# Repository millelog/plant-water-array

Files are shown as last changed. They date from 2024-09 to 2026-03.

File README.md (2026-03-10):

# Plant Water Array

Distributed plant moisture monitoring system with custom ESP32 sensors, a Python backend, and a React frontend. Devices self-register via captive portal WiFi provisioning, send periodic moisture readings, and receive code updates pushed over the LAN.

**Live demo:** [plants.loganmiller.dev](https://plants.loganmiller.dev) — click **Browse as Guest** to explore the UI with sample data (read-only).

## Features

- **Real-time moisture monitoring** — ESP32 sensors report soil moisture on a configurable interval
- **Watering log** — manual logging with notes, or auto-detection from sharp moisture spikes
- **Push notifications** — alerts via [ntfy.sh](https://ntfy.sh) when plants need water or devices go offline
- **Data insights** — drying rate analysis, aggregated trends, multi-sensor comparison charts, CSV export
- **Dashboard** — sortable/filterable plant cards, weather widget, kiosk mode for wall-mounted displays
- **Push deploys** — update device firmware over LAN with `deploy.py` (atomic file swap, SHA-256 verified)
- **Captive portal provisioning** — new devices create a WiFi AP for zero-config setup
- **PWA** — installable on mobile, responsive layout with bottom navigation
- **Light/dark themes** — dark "Greenhouse Control Room" theme by default, light mode available
- **JWT authentication** — admin login with guest demo mode
- **Database maintenance** — backup downloads, configurable data retention, health stats
- **Custom PCB** — KiCad schematic and board files in `pcb/`

## Architecture

```
ESP32 sensors  ──POST readings──▶  FastAPI backend  ◀──polls──  React frontend
  (MicroPython)                     (SQLite DB)                  (Vite + Tailwind)
```

| Component | Directory | Stack |
|---|---|---|
| Backend | `backend/` | FastAPI, SQLAlchemy, SQLite |
| Frontend | `frontend/` | React 18, TypeScript, Tailwind, Radix UI, Recharts |
| Embedded | `embeded-src/` | MicroPython on ESP32 |
| Hardware | `pcb/` | KiCad schematic + PCB |
| Deploy tool | `deploy.py` | CLI script, pushes code to devices over LAN |

## Development

### Backend
```bash
cd backend
source .venv/bin/activate
pip install -r requirements.txt
uvicorn main:app --reload --host 0.0.0.0 --port 8000
```
API docs at http://localhost:8000/docs

### Frontend
```bash
cd frontend
pnpm install
pnpm dev          # Vite dev server on port 5173
pnpm build        # TypeScript compile + Vite bundle
pnpm lint         # ESLint
```

### ESP32 Flashing
```bash
python flash_esp.py               # Auto-detect port, flash MicroPython, upload source
python flash_esp.py --sync-only   # Upload source files only
python -m mpremote connect <port> repl   # Serial console
```

### Deploying Code to Devices
```bash
python deploy.py                  # Push embeded-src/*.py to all devices over LAN
python deploy.py --dry-run        # Preview what would be deployed
python deploy.py --server URL     # Override backend URL
```

### Docker Compose
```bash
docker compose up --build         # Run backend + frontend together
```
See [docs/DEPLOYMENT.md](docs/DEPLOYMENT.md) for production deployment details.

## Data Flow

1. ESP32 boots → connects WiFi (or starts captive portal for provisioning)
2. Starts update server on port 8266 for receiving push deploys
3. Registers itself via `POST /devices/register_device`, then registers sensors via `POST /sensors/`
4. Main loop: reads moisture → `POST /readings`, heartbeat every 300s
5. Backend checks thresholds on new readings → creates alerts, sends ntfy notifications
6. Frontend polls backend APIs to display devices, readings, alerts
7. Developer runs `python deploy.py` → pushes code to all online devices, devices reboot with new code

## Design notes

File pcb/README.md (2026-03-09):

# Plant Water Array — PCB Design

Breakout board for ESP32 DevKit V1 with OLED display and 5 moisture sensor connectors.

## Board Summary

```
+--------------------------------------------------+
|                                                  |
|  [OLED 4-pin]              [ESP32 DevKit V1]    |
|   GND VCC SCL SDA           L-socket  R-socket  |
|                              (1x15)    (1x15)    |
|                                                  |
|  [J_S1] [J_S2] [J_S3] [J_S4] [J_S5]           |
|   G34    G35    G36    G39    G32               |
+--------------------------------------------------+
```

## Parts List (per board)

### PCB Connectors (solder onto the board)

| Part | Qty | Search Term | Notes |
|---|-----|---|---|
| 1x15 Female Pin Socket (2.54mm) | 2 | "1x15 pin socket 2.54mm" | ESP32 DevKit mounts into these |
| 1x4 Female Pin Socket (2.54mm) | 1 | "1x4 pin socket 2.54mm" | SSD1306 OLED plugs in here |
| JST-XH 3-pin vertical header (B3B-XH-A) | 5 | "JST XH 3 pin male header vertical" | Board-side sensor connectors |

### Sensor Cable Parts (per sensor, 5 per board)

| Part | Qty | Search Term | Notes |
|---|-----|---|---|
| JST-XH 3-pin plug housing (XHP-3) | 1 | "JST XH 3 pin female housing" | Mates with B3B-XH-A header |
| JST-XH crimp contacts (SXH-001T-P0.6) | 3 | "JST XH crimp terminal" | One per wire |
| 3-conductor wire (22-26 AWG) | ~1m | "3 conductor 24AWG wire" | Length as needed, up to ~2m |

### Quantities for 5 Boards

| Part | Total Qty |
|---|---|
| 1x15 Female Pin Socket | 10 |
| 1x4 Female Pin Socket | 5 |
| JST-XH 3-pin header (B3B-XH-A) | 25 |
| JST-XH 3-pin housing (XHP-3) | 25 |
| JST-XH crimp contacts | 75 |
| 3-conductor wire | ~25m |

### Where to Buy

- **Amazon** (fastest) — search "JST XH connector kit" (~$10-15 for assorted kit with headers + housings + crimp pins). Separately get a pack of "female pin header socket 2.54mm" (~$5-7).
- **AliExpress** (cheapest, 2-3 week shipping) — same searches, about 1/3 the price.
- **Digikey / Mouser** (exact part numbers, reliable) — B3B-XH-A ~$0.15ea, XHP-3 ~$0.10ea, SXH-001T-P0.6 ~$0.05ea, pin sockets ~$0.50ea.

A JST crimp tool (~$25) is helpful but you can solder wires directly to the crimp contacts instead.

## Pin Mapping

| Connector | Pin 1 | Pin 2 | Pin 3 | ESP32 GPIO |
|---|---|---|---|---|
| J_S1 | GND | 3V3 | SIG | GPIO 34 |
| J_S2 | GND | 3V3 | SIG | GPIO 35 |
| J_S3 | GND | 3V3 | SIG | GPIO 36 (VP) |
| J_S4 | GND | 3V3 | SIG | GPIO 39 (VN) |
| J_S5 | GND | 3V3 | SIG | GPIO 32 |
| J_OLED | GND | 3V3 | SCL (GPIO 22) | SDA (GPIO 21) |

## Generating the Netlist

```bash
cd pcb/
python generate_netlist.py
# Produces plant_water_array.net
# Open KiCad PCB Editor → File → Import Netlist
```

No dependencies required — just Python.

## PCB Layout Tips

- ESP32 socket headers in the center (25.4mm apart, verify with your DevKit)
- OLED header on top edge
- JST-XH connectors along bottom or side edge
- Keep traces wide (0.5mm+)
- Pour a ground plane on the back copper layer (select B.Cu → Place → Add Filled Zone → net GND)

## Ordering PCBs (JLCPCB)

1. Export Gerbers from KiCad: **File → Fabrication Outputs → Gerbers**, then **Generate Drill Files**
2. Zip the `gerber_out/` folder
3. Go to **jlcpcb.com** → **Order Now** → upload the zip

### JLCPCB Settings

| Setting | Value |
|---|---|
| Base Material | FR-4 |
| Layers | 2 |
| PCB Qty | 5 |
| PCB Thickness | 1.6mm |
| PCB Color | Green (cheapest) |
| Surface Finish | HASL (or LeadFree HASL) |
| Copper Weight | 1 oz |
| Everything else | Default |

Cost: ~$2-5 + shipping ($1-5 standard, ~$15-20 DHL express).

## Sensor Cable Assembly

Each sensor cable is a 3-wire bundle with a JST-XH plug on the board end:

```
Sensor                Board End
┌─────────┐         ┌──────────┐
│ S (sig) │─────────│ Pin 3    │
│ + (VCC) │─────────│ Pin 2    │
│ - (GND) │─────────│ Pin 1    │
└─────────┘         └──────────┘
                    JST-XH plug
```

Use 3-conductor cable (ribbon cable or twisted triple) — can run 1-2 meters without issues for analog signals.

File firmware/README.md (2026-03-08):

# Firmware

## Prerequisites

```
pip install esptool mpremote pyserial
```

## Flash the ESP32

From the repository root, with the ESP32 connected via USB:

```
python flash_esp.py
```

This will automatically:
1. Detect the connected ESP32 serial port (Windows COM ports or Linux /dev/ttyUSB*)
2. Erase the flash
3. Write the MicroPython firmware
4. Upload `main.py`, `captive_portal.py`, and `config.py` from `embeded-src/`

Make sure you have a `embeded-src/config.py` before running (copy from `config.py.example` and fill in your values).

## Manual commands

If you need to run the steps individually:

```
python -m esptool --chip esp32 --port <PORT> erase_flash
python -m esptool --chip esp32 --port <PORT> write_flash -z 0x1000 firmware/ESP32_GENERIC-20240602-v1.23.0.bin
python -m mpremote connect <PORT> cp embeded-src/main.py :main.py
python -m mpremote connect <PORT> cp embeded-src/captive_portal.py :captive_portal.py
python -m mpremote connect <PORT> cp embeded-src/config.py :config.py
python -m mpremote connect <PORT> reset
```

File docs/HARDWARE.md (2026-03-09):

# Hardware

## Platform

ESP-WROOM-32 DevKit running MicroPython.

## Pin Reference

| Component | Pin(s) | Notes |
|---|---|---|
| Moisture sensors (ADC1) | GPIO 32, 33, 34, 35, 36, 39 | Up to 6 sensors per device. Default: `[34]` in config. |
| OLED display SCL | GPIO 22 | SSD1306 128x64 I2C (optional) |
| OLED display SDA | GPIO 21 | |
| BOOT button | GPIO 0 | Hold 5s for factory reset |

**Do not use ADC2 pins** (GPIO 0, 2, 4, 12-15, 25-27) — they do not work when WiFi is active.

## Moisture Sensors

3-pin capacitive analog sensors (Elecbee/icomcu or compatible):

| Pin | Connection |
|-----|---|
| S (signal) | Any ADC1 GPIO (see table above) |
| + (VCC) | 3V3 |
| - (GND) | GND |

ADC is configured with 11dB attenuation for full 0-3.6V range. Readings are averaged over 10 samples.

### Default Calibration

| Condition | Raw ADC Value |
|---|---|
| Dry (air) | 0 |
| Wet (water) | 1500 |

Per-sensor calibration can be set from the frontend via the Calibration Wizard.

## OLED Display (Optional)

SSD1306 128x64 I2C (GME12864 compatible). Will not fail if not wired.

| Pin | Connection |
|-----|---|
| GND | GND |
| VCC | 3V3 |
| SCL | GPIO 22 |
| SDA | GPIO 21 |

Requires the `ssd1306` MicroPython module (`import mip; mip.install("ssd1306")`).

Display layout (128x64 @ 8x8 font = 16 chars x 8 lines):
- Line 0: device name + alert count
- Line 1: separator
- Lines 2-7: sensor rows (name + moisture %), paginated every 5s when >6 sensors

## BOOT Button (Factory Reset)

Hold the BOOT button (GPIO 0) for 5 seconds on startup to erase saved config and re-enter captive portal provisioning mode.

## Enclosure

- **ESP32 Case:** [ESP32 Case on Thingiverse](https://www.thingiverse.com/thing:5100184)

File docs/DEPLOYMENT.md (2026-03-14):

# Production Deployment (Coolify on gpu1)

The app runs on **gpu1** via Coolify (Docker Compose), with Traefik handling reverse proxy and SSL.

| Service | URL | Internal Port |
|---|-----|---|
| Frontend | https://plants.loganmiller.dev | 80 (nginx) |
| Backend API | https://plants-api.loganmiller.dev | 8000 (uvicorn) |
| Backend LAN | http://192.168.70.100:8321 | 8000 (for ESP32 devices) |

## DNS

Wildcard `*.loganmiller.dev` points to gpu1's public IP. Coolify/Traefik handles routing by hostname and provisions Let's Encrypt SSL certificates automatically.

## Data Storage

The SQLite database is stored on **nas1** (Unraid) via NFS:

```
nas1:/mnt/user/appdata/plant-water-array/  →  gpu1:/mnt/nas1/appdata/plant-water-array/  →  container:/data/
```

The `docker-compose.yml` bind-mounts this path so the DB persists across container rebuilds and lives on redundant storage (RAID1 SSD pool).

## ESP32 LAN Access

Backend port 8321 on gpu1 is exposed for ESP32 devices on the LAN. Devices use:
```python
# embeded-src/config.py
SERVER_URL = "http://192.168.70.100:8321"
```

Deploy script targets the same endpoint:
```bash
python deploy.py --server http://192.168.70.100:8321
```

## Coolify Notes

- **Source:** GitHub repo `millelog/plant-water-array`, branch `main`, auto-deploy enabled
- **Compose path:** `/docker-compose.yml`
- **Domains:** Set per-service in Coolify UI (frontend and backend separately)
- After changing domains in Coolify, click **"Reload Compose File"** then redeploy — Coolify injects Traefik labels on reload, not just on domain save

## Migrating the Database

```bash
scp backend/backend.db millelog@gpu1.lan:/tmp/backend.db
ssh millelog@gpu1.lan
docker ps | grep backend       # find container ID
docker cp /tmp/backend.db <container_id>:/data/backend.db
docker restart <container_id>
rm /tmp/backend.db
```

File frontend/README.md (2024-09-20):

## File Structure
```
lua
frontend/
├── index.html
├── package.json
├── postcss.config.js
├── tailwind.config.js
├── vite.config.js
├── src/
│   ├── App.jsx
│   ├── main.jsx
│   ├── index.css
│   ├── api/
│   │   ├── api.js
│   ├── components/
│   │   ├── Navbar.jsx
│   │   ├── Sidebar.jsx
│   │   ├── DataTable.jsx
│   │   ├── AlertCard.jsx
│   ├── pages/
│   │   ├── Dashboard.jsx
│   │   ├── Devices.jsx
│   │   ├── Sensors.jsx
│   │   ├── Readings.jsx
│   │   ├── Alerts.jsx
│   │   ├── Settings.jsx
│   └── routes.jsx
└── README.md
```
index.html: The HTML template file.
package.json: Contains project dependencies and scripts.
tailwind.config.js: Tailwind CSS configuration.
vite.config.js: Vite configuration file.
src/: Contains all the React code.
App.jsx: The main application component.
main.jsx: Entry point for React.
index.css: Global CSS styles.
api/: API utility functions for interacting with the backend.
components/: Reusable UI components.
pages/: Different pages/routes of the application.
routes.jsx: Defines the routing for the application.

##Running the Frontend
Navigate to the frontend directory:
```
bash
cd frontend
```
Install Dependencies:

If you haven't already installed the dependencies during setup:
```
bash
npm install
```
Run the Application:
```
bash
npm run dev
```
Access the Frontend:

Open your browser and navigate to:
```
arduino
http://localhost:5173
```
(Vite's default port is 5173)

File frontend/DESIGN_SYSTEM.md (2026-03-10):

# Plant Water Array — Design System

This document defines the visual language, design tokens, and component patterns for the Plant Water Array frontend. All future UI work should adhere to these conventions.

## Aesthetic Direction

**"Greenhouse Control Room"** — a dark-mode monitoring interface that balances the organic nature of plant care with the precision of sensor data. The design pairs botanical serif typography with monospaced data readouts, emerald green accents against deep slate surfaces, and subtle animated status indicators.

### Core Principles

1. **Data-forward** — sensor readings, device status, and alerts are the primary content. Present them prominently using monospaced numerals and color-coded values.
2. **Dark & atmospheric** (default) — deep slate backgrounds with subtle topographic texture. Cards and surfaces float with soft shadows rather than hard borders. Light mode available via navbar toggle.
3. **Organic accents** — emerald green primary accent evokes plant life. Amber/gold for warnings (soil/drought). Coral red for danger/alerts.
4. **Restraint in motion** — animate on entry (fade-in, slide-up) and status indicators (pulse). Avoid gratuitous motion elsewhere.

---

## Typography

Three font families, loaded from Google Fonts:

| Role | Font | Weight(s) | Usage |
|---|---|---|---|
| **Display** | `Instrument Serif` | 400, italic | Page titles (`.page-title`), brand name, modal headings |
| **Body** | `Plus Jakarta Sans` | 300–700 | All UI text, labels, buttons, paragraphs |
| **Mono** | `Space Mono` | 400, 700 | Sensor values, timestamps, device IDs, badges, ADC readings |

### Tailwind Classes

```
font-display  →  Instrument Serif
font-body     →  Plus Jakarta Sans (default body font)
font-mono     →  Space Mono
```

### Conventions

- Page headings: `font-display text-3xl` (use `.page-title` utility)
- Section headings: `font-body text-lg font-semibold` (use `.section-title` utility)
- Data values: `font-mono text-accent tabular-nums` (use `.data-value` utility)
- Labels/captions: `text-xs font-mono text-text-muted uppercase tracking-wider`

---

## Color Palette

All colors are defined as Tailwind theme extensions. Use semantic names, not raw hex values.

### Backgrounds

| Token | Hex | Usage |
|---|-----|---|
| `canvas` | `#0c1117` | Page background, body |
| `canvas-50` | `#111920` | Sidebar, navbar, elevated bg |
| `canvas-100` | `#161f28` | Input backgrounds, nested cards |
| `canvas-200` | `#1c2732` | Hover states, badges |
| `canvas-300` | `#24303d` | Active states |

### Surfaces

| Token | Usage |
|---|---|
| `surface` (`#182028`) | Card backgrounds |
| `surface-hover` (`#1e2a34`) | Card hover state |
| `surface-border` | Default border (10% opacity) |
| `surface-border-hover` | Hover border (22% opacity) |

### Accent Colors

| Token | Hex | Usage |
|---|-----|---|
| `accent` | `#34d399` | Primary action, online status, healthy moisture |
| `accent-dim` | `#10b981` | Hover state for primary accent |
| `accent-glow` | `rgba(52,211,153,0.12)` | Glow backgrounds for accent elements |
| `soil` | `#d97706` | Warning state, low moisture, provisioning |
| `soil-dim` | `#b45309` | Hover state for soil accent |
| `soil-glow` | `rgba(217,119,6,0.12)` | Glow backgrounds for warnings |
| `danger` | `#f87171` | Error state, critical alerts, delete actions |
| `danger-dim` | `#ef4444` | Hover state for danger |
| `danger-glow` | `rgba(248,113,113,0.12)` | Glow backgrounds for errors |

### Text

| Token | Hex | Usage |
|---|-----|---|
| `text` | `#e8edf3` | Primary text (headings, names) |
| `text-secondary` | `#8899a6` | Secondary text (table cells, descriptions) |
| `text-muted` | `#5c6f7e` | Tertiary text (labels, captions, placeholders) |

---

## Component Classes

Defined in `src/index.css` as Tailwind `@layer components`. Use these instead of writing one-off styles.

### `.card`

The primary surface container. Dark background with subtle border and shadow.

```html
<div class="card p-5">
  <!-- content -->
</div>
```

- Includes hover transition for border and shadow
- Use `p-5` for standard padding, `p-6` for spacious layouts

### `.btn`, `.btn-primary`, `.btn-secondary`, `.btn-danger`, `.btn-ghost`

Button variants. All include focus rings, disabled states, and active scale.

```html
<button class="btn-primary">Save</button>
<button class="btn-secondary text-xs">Cancel</button>
<button class="btn-danger text-xs py-1.5 px-3">Delete</button>
<button class="btn-ghost text-xs">Dismiss</button>
```

### `.input`

Form inputs and selects. Dark background with accent-colored focus ring.

```html
<input type="text" class="input" placeholder="..." />
<select class="input">...</select>
```

Select elements automatically get a custom dropdown chevron.

### `.badge`

Small label/tag for metadata (version numbers, status, etc).

```html
<span class="badge bg-canvas-200 text-text-muted border border-surface-border">v1.0</span>
<span class="badge bg-accent-glow text-accent border border-accent/15">Calibrated</span>
```

### `.status-dot`

Animated status indicator. 8px circle with optional pulse animation.

```html
<span class="status-dot status-dot--online"></span>    <!-- green, pulsing -->
<span class="status-dot status-dot--offline"></span>    <!-- muted gray -->
<span class="status-dot status-dot--provisioning"></span> <!-- amber, fast pulse -->
```

### `.moisture-bar`

Horizontal progress bar for moisture percentage. Uses a gradient fill (amber → green).

```html
<div class="moisture-bar">
  
</div>
```

### `.data-value`

Inline monospaced accent text for numbers and data.

```html
<span class="data-value text-sm">192.168.1.42</span>
```

### `.page-title`, `.section-title`

Heading utilities. Page title uses the serif display font; section title uses the body font.

---

## Layout

### App Shell

- **Sidebar**: 240px (`w-60`), fixed left, `bg-canvas-50`, border-right
- **Navbar**: Full width header inside content area, shows current page title (serif font) and system status
- **Main content**: Scrollable area with `px-6 py-6 lg:px-10` padding

### Page Structure

Every page follows this pattern:

```tsx
<div className="space-y-6 animate-fade-in">
  {/* Optional stats/controls row */}
  {/* Main content cards */}
</div>
```

### Cards & Tables

- Use `<DataTable>` for tabular data — it wraps itself in `.card`
- Use `.card p-5` for form sections, stats, empty states
- Table headers: `text-[11px] font-mono text-text-muted uppercase tracking-wider`

---

## Animations

Defined in `tailwind.config.js`:

| Class | Effect | Duration |
|---|---|---|
| `animate-fade-in` | Opacity 0→1 | 400ms |
| `animate-slide-up` | Opacity + translateY(12px→0) | 400ms |
| `animate-slide-in-left` | Opacity + translateX(-12px→0) | 300ms |
| `animate-pulse-slow` | Slow pulse | 3s infinite |

### Usage Patterns

- Page root: `animate-fade-in`
- Staggered list items: `animate-slide-up` with `style={{ animationDelay: '${i * 80}ms' }}`
- Status dots: CSS `statusPulse` keyframe (defined in index.css)

---

## Shadows

| Token | Usage |
|---|---|
| `shadow-card` | Default card shadow |
| `shadow-card-hover` | Card hover shadow (deeper) |
| `shadow-glow` | Subtle accent glow |
| `shadow-glow-accent` | Stronger accent glow (brand mark, highlights) |

---

## Theming

The design system supports both dark and light modes via CSS custom properties.

### How It Works

All colors are defined as CSS custom properties in `:root` (dark theme) and `.light-theme` (light theme override) in `index.css`. Tailwind references these variables, so all existing utility classes automatically adapt.

- **Toggle**: Sun/moon button in navbar, visible on all screen sizes
- **Persistence**: `localStorage.getItem('theme')` — defaults to `'dark'`
- **Flash prevention**: Inline `<script>` in `index.html` applies theme class before first paint
- **Transition**: 200ms ease on background-color, color, border-color, box-shadow

### CSS Variable Format

Solid colors use space-separated RGB triplets for Tailwind alpha modifier support:
```css
:root { --accent: 52 211 153; }
/* Usage: bg-accent/20 → rgb(52 211 153 / 0.2) */
```

Pre-baked opacity colors use full `rgba()`:
```css
:root { --accent-glow: rgba(52, 211, 153, 0.12); }
```

### useTheme() Hook

```tsx
import { useTheme } from '@/context/ThemeContext';

const { theme, toggleTheme, chartColors } = useTheme();
```

- `theme`: `'dark' | 'light'`
- `toggleTheme()`: switches theme and persists to localStorage
- `chartColors`: memoized color map for Recharts components (hex/rgba values)

### Light Mode Palette

| Token | Dark | Light |
|---|---|---|
| canvas | `#0c1117` | `#f8fafb` |
| surface | `#182028` | `#ffffff` |
| accent | `#34d399` | `#10b981` |
| soil | `#d97706` | `#b45309` |
| danger | `#f87171` | `#dc2626` |
| text | `#e8edf3` | `#1a2332` |
| text-secondary | `#8899a6` | `#526170` |
| text-muted | `#5c6f7e` | `#8899a6` |

---

## Charts (Recharts)

The `SensorReadingsGraph` component uses an AreaChart with these conventions:

- **Background**: transparent (inherits dark card surface)
- **Grid**: `rgba(148, 163, 184, 0.06)` dashed lines
- **Line/Area**: `#34d399` stroke, gradient fill fading to transparent
- **Tooltip**: dark background (`#182028`), accent-bordered, rounded-xl
- **Axis text**: `#5c6f7e`, 11px, Space Mono
- **Active dot**: emerald fill with dark stroke

---

## Icons

Using `@heroicons/react/24/outline`. Standard size is `w-[18px] h-[18px]` in navigation, `w-4 h-4` in inline contexts.

Custom SVG icons are used for:
- Brand leaf/plant mark (Sidebar)
- Device icon (DeviceCard, Devices empty state)

---

## Do's and Don'ts

**Do:**
- Use semantic color tokens (`text-accent`, `bg-danger-glow`) not raw Tailwind colors (`text-green-400`)
- Use `.card`, `.btn-*`, `.input` component classes
- Use `font-mono` for any numeric data or technical identifiers
- Add `animate-fade-in` to page root elements
- Use `space-y-6` for page-level vertical rhythm

**Don't:**
- Use hardcoded hex colors — use CSS variables and Tailwind tokens instead
- Use generic fonts (Inter, Roboto, Arial) — use the three defined families
- Add heavy animations or transitions beyond the defined set
- Use raw `bg-gray-*` or `text-gray-*` — use the `canvas-*`, `surface-*`, and `text-*` tokens
- Create one-off button styles — extend the `.btn-*` system if needed

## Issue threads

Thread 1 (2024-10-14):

Maybe dont expose environment keys in your repo?

developerJuiceLozzoc, 2024-10-14:
https://github.com/millelog/plant-water-array/blob/35f50aee433cbc810b5646a21eb76902addc3070/embeded-src/main.py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

millelog, 2024-10-14:
Ah thank you! The plan is to have the ESP32 host its own wifi to connect to and configure with these secrets when you first set them up. Was doing this for testing and didn't realize I committed it.

Resolved with commit and pruned from git history: https://github.com/millelog/plant-water-array/commit/48cd8716637532b7836a2b9f8a80c8a77febaf37

Going to delete this issue so the secret isn't in this thread either.

Closed 2024-10-14.

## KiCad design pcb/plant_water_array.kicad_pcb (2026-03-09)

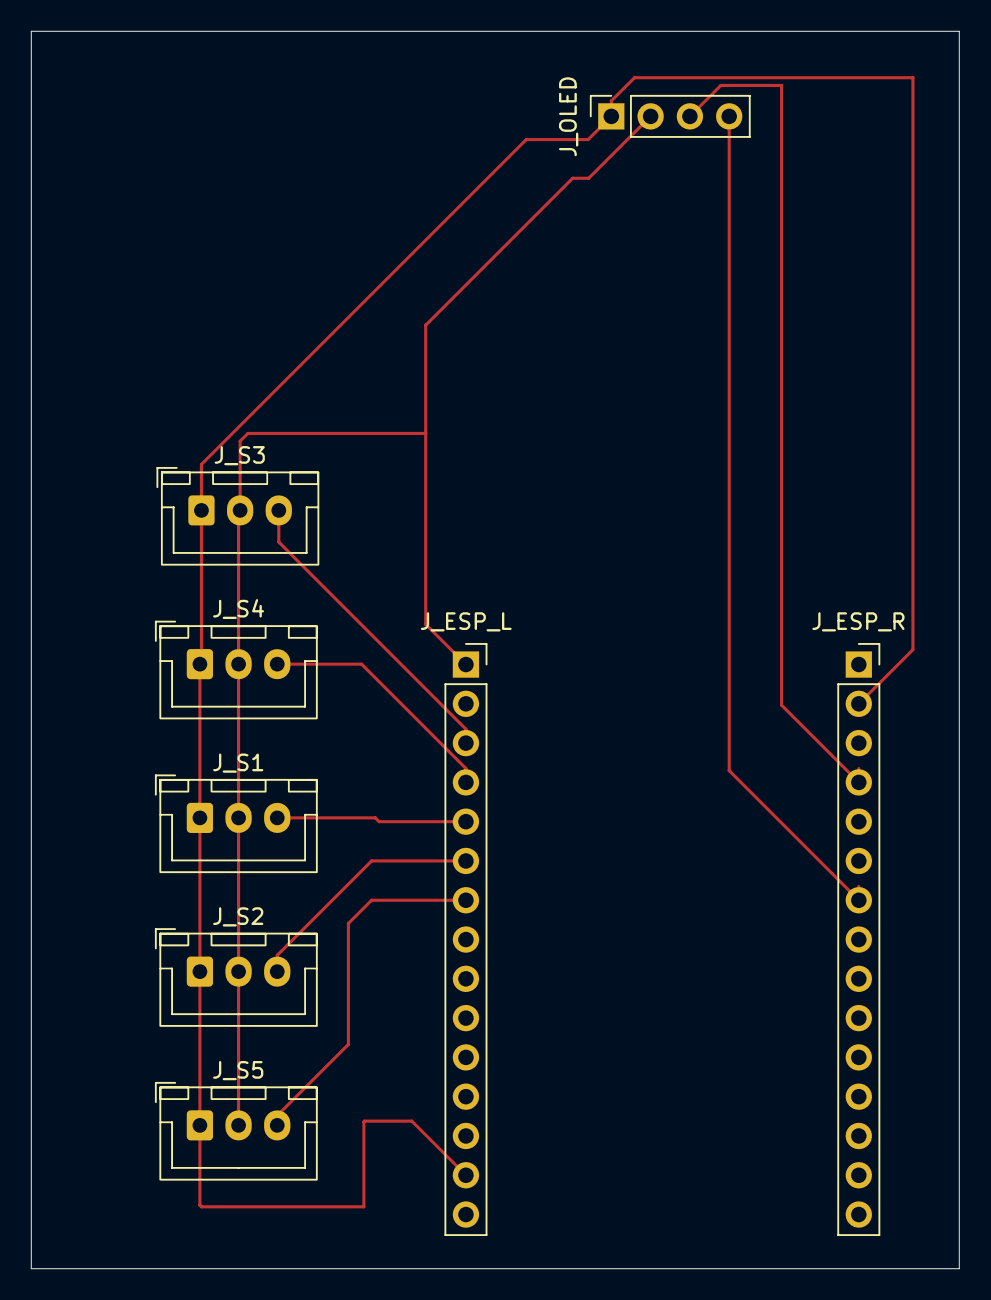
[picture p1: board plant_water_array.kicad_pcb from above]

Board: 2 copper layers, 60.0 x 80.0 mm, 8 parts (0 on the bottom side), 9 nets.

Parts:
J_ESP_L: ESP32_Left; PinSocket_1x15_P2.54mm_Vertical
J_ESP_R: ESP32_Right; PinSocket_1x15_P2.54mm_Vertical
J_OLED: SSD1306_OLED; PinSocket_1x04_P2.54mm_Vertical
J_S1: Moisture_G34; JST_XH_B3B-XH-A_1x03_P2.50mm_Vertical
J_S2: Moisture_G35; JST_XH_B3B-XH-A_1x03_P2.50mm_Vertical
J_S3: Moisture_G36; JST_XH_B3B-XH-A_1x03_P2.50mm_Vertical
J_S4: Moisture_G39; JST_XH_B3B-XH-A_1x03_P2.50mm_Vertical
J_S5: Moisture_G32; JST_XH_B3B-XH-A_1x03_P2.50mm_Vertical

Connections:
+3V3: J_ESP_L.1, J_OLED.2, J_S1.2, J_S2.2, J_S3.2, J_S4.2, J_S5.2
GND: J_ESP_L.14, J_ESP_R.2, J_OLED.1, J_S1.1, J_S2.1, J_S3.1, J_S4.1, J_S5.1
I2C_SCL: J_ESP_R.4, J_OLED.3
I2C_SDA: J_ESP_R.7, J_OLED.4
SENSOR1_G34: J_ESP_L.5, J_S1.3
SENSOR2_G35: J_ESP_L.6, J_S2.3
SENSOR3_G36: J_ESP_L.3, J_S3.3
SENSOR4_G39: J_ESP_L.4, J_S4.3
SENSOR5_G32: J_ESP_L.7, J_S5.3

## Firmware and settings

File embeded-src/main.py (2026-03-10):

import network  # type: ignore
import ubinascii  # type: ignore
import urequests  # type: ignore
import machine  # type: ignore
import time
import random
import os


sta_if = network.WLAN(network.STA_IF)

# Server-synced config cache (updated via heartbeat responses)
server_config = {
    "reading_interval": None,
    "sensors": {},  # sensor_id -> {name, calibration_dry, calibration_wet, threshold_min, threshold_max}
}

HEARTBEAT_INTERVAL = 300  # seconds


def get_mac():
    return ubinascii.hexlify(sta_if.config('mac'), ':').decode()


def get_ip():
    if sta_if.isconnected():
        return sta_if.ifconfig()[0]
    return None


def get_firmware_version():
    try:
        from _version import GIT_COMMIT
        return GIT_COMMIT
    except ImportError:
        return "unknown"


def is_configured():
    try:
        import config
        if not hasattr(config, 'WIFI_SSID') or config.WIFI_SSID in ("", "Your_SSID_Here"):
            return False
        if not hasattr(config, 'SERVER_URL') or config.SERVER_URL in ("", "http://your.server.url:port"):
            return False
        return True
    except ImportError:
        return False


def check_factory_reset():
    pin = machine.Pin(0, machine.Pin.IN, machine.Pin.PULL_UP)
    if pin.value() == 0:
        print("BOOT button pressed, hold for 5 seconds to factory reset...")
        start = time.time()
        while pin.value() == 0:
            if time.time() - start >= 5:
                print("Factory reset triggered! Deleting config.py...")
                try:
                    os.remove("config.py")
                    print("config.py deleted.")
                except OSError:
                    print("config.py not found, already clean.")
                time.sleep(1)
                machine.reset()
            time.sleep(0.1)
        print("BOOT button released before 5 seconds, continuing normal boot.")


def connect_wifi():
    import config
    if not sta_if.isconnected():
        print('Connecting to WiFi...')
        sta_if.active(True)
        sta_if.connect(config.WIFI_SSID, config.WIFI_PASSWORD)
        for _ in range(20):
            if sta_if.isconnected():
                break
            time.sleep(0.5)
    if sta_if.isconnected():
        print('WiFi connected')
        print('Network config:', sta_if.ifconfig())
    else:
        print('WiFi connection failed, falling back to captive portal...')
        import captive_portal
        captive_portal.run_portal()


def ensure_wifi():
    if not sta_if.isconnected():
        print('WiFi disconnected, reconnecting...')
        connect_wifi()
    return sta_if.isconnected()


def get_device_headers():
    """Return auth headers for backend API calls."""
    import config
    key = getattr(config, 'DEVICE_API_KEY', None)
    if key:
        return {"X-Device-Key": key}
    return {}


def http_request(method, url, max_retries=3, **kwargs):
    # Inject device auth headers if not already provided
    headers = kwargs.pop("headers", {}) or {}
    auth_headers = get_device_headers()
    for k, v in auth_headers.items():
        if k not in headers:
            headers[k] = v
    if headers:
        kwargs["headers"] = headers

    for attempt in range(max_retries):
        try:
            if method == "GET":
                response = urequests.get(url, **kwargs)
            elif method == "POST":
                response = urequests.post(url, **kwargs)
            else:
                raise ValueError(f"Unsupported method: {method}")
            return response
        except Exception as e:
            print(f"HTTP {method} {url} attempt {attempt + 1} failed: {e}")
            if attempt < max_retries - 1:
                delay = (2 ** attempt) + random.uniform(0, 1)
                print(f"Retrying in {delay:.1f}s...")
                time.sleep(delay)
            else:
                print(f"All {max_retries} attempts failed for {method} {url}")
                raise


def ping_server():
    import config
    try:
        print(f"Attempting to ping server at {config.SERVER_URL}/ping")
        response = http_request("GET", config.SERVER_URL + "/ping", timeout=10)
        print(f"Received response with status code: {response.status_code}")
        if response.status_code == 200:
            print("Server is reachable")
            response.close()
            return True
        else:
            print(f"Server returned unexpected status code: {response.status_code}")
            response.close()
            return False
    except Exception as e:
        print(f"Error pinging server: {str(e)}")
        return False


def register_with_server():
    import config
    mac = get_mac()
    ip = get_ip()
    data = {
        "name": config.DEVICE_NAME,
        "device_id": mac,
        "firmware_version": get_firmware_version(),
        "ip_address": ip,
        "mac_address": mac,
        "deploy_token": getattr(config, 'DEPLOY_TOKEN', None),
    }
    try:
        response = http_request("POST", config.SERVER_URL + "/devices/register_device", json=data)
        if response.status_code == 200:
            device_info = response.json()
            print("Device registered successfully. Device ID:", device_info.get('device_id'))
            response.close()
            return device_info.get('device_id')
        else:
            print(f"Error registering device. Status code: {response.status_code}")
            response.close()
            return None
    except Exception as e:
        print("Error registering device:", str(e))
        return None


def setup_sensors():
    """Initialize ADC on each pin listed in config.SENSOR_PINS.

    ESP32 ADC1 pins that work with WiFi active: 32, 33, 34, 35, 36, 39
    Max 6 moisture sensors per ESP32.
    """
    import config
    pins = getattr(config, 'SENSOR_PINS', [34])
    sensors = []
    for pin_num in pins:
        try:
            adc = machine.ADC(machine.Pin(pin_num))
            adc.atten(machine.ADC.ATTN_11DB)  # Full 0-3.6V range
            adc.read()  # Test read
            name = f"Moisture_GPIO{pin_num}"
            sensors.append({"name": name, "pin": pin_num, "adc": adc})
            print(f"ADC initialized on GPIO {pin_num}")
        except Exception as e:
            print(f"Failed to init ADC on GPIO {pin_num}: {e}")
    print(f"Initialized {len(sensors)} sensor(s)")
    return sensors


def read_moisture(adc, samples=10):
    """Read moisture % from ADC, averaged over multiple samples.

    Returns (percentage, raw_average).
    Calibration values ADC_DRY / ADC_WET come from config.
    """
    import config
    total = 0
    for _ in range(samples):
        total += adc.read()
        time.sleep_ms(10)
    raw = total // samples

    dry_val = getattr(config, 'ADC_DRY', 0)
    wet_val = getattr(config, 'ADC_WET', 1500)

    if dry_val == wet_val:
        return 0.0, raw

    pct = ((dry_val - raw) / (dry_val - wet_val)) * 100.0
    pct = max(0.0, min(100.0, pct))
    return round(pct, 1), raw


def register_sensor(device_id, sensor_name, sensor_id):
    import config
    data = {
        "device_id": device_id,
        "name": sensor_name,
        "sensor_id": sensor_id
    }
    try:
        response = http_request("POST", config.SERVER_URL + "/sensors/", json=data)
        if response.status_code == 200:
            sensor_info = response.json()
            print(f"Sensor {sensor_name} registered successfully. Sensor ID:", sensor_info.get('id'))
            response.close()
            return sensor_info.get('id')
        else:
            print(f"Error registering sensor {sensor_name}. Status code: {response.status_code}")
            response.close()
            return None
    except Exception as e:
        print(f"Error registering sensor {sensor_name}:", str(e))
        return None


def send_moisture_reading(device_id, sensor_id, moisture, raw_adc=None):
    import config
    data = {
        "device_id": device_id,
        "sensor_id": sensor_id,
        "moisture": moisture
    }
    if raw_adc is not None:
        data["raw_adc"] = raw_adc
    try:
        response = http_request("POST", config.SERVER_URL + "/readings", json=data)
        print(f"Moisture reading sent for sensor {sensor_id}. Server response:", response.text)
        response.close()
    except Exception as e:
        print(f"Error sending moisture reading for sensor {sensor_id}:", str(e))


def send_heartbeat(device_id):
    import config
    data = {
        "firmware_version": get_firmware_version(),
        "ip_address": get_ip(),
        "mac_address": get_mac()
    }
    try:
        response = http_request("POST", config.SERVER_URL + f"/devices/{device_id}/heartbeat", json=data)
        if response.status_code == 200:
            print("Heartbeat sent successfully")
            try:
                heartbeat_data = response.json()
                response.close()
                return heartbeat_data
            except Exception:
                response.close()
                return None
        response.close()
    except Exception as e:
        print(f"Error sending heartbeat: {e}")
    return None


def apply_server_config(heartbeat_data, registered_sensors):
    global server_config
    if not heartbeat_data:
        return
    if "reading_interval" in heartbeat_data:
        server_config["reading_interval"] = heartbeat_data["reading_interval"]
        print(f"Config sync: reading_interval={heartbeat_data['reading_interval']}s")
    for sc in heartbeat_data.get("sensors", []):
        sid = sc.get("sensor_id")
        if sid is not None:
            server_config["sensors"][sid] = {
                "name": sc.get("name"),
                "calibration_dry": sc.get("calibration_dry"),
                "calibration_wet": sc.get("calibration_wet"),
                "threshold_min": sc.get("threshold_min"),
                "threshold_max": sc.get("threshold_max"),
            }
            # Update sensor name in registered_sensors list
            for s in registered_sensors:
                if s["sensor_id"] == sid and sc.get("name"):
                    s["server_name"] = sc["name"]


def get_reading_interval():
    import config
    if server_config["reading_interval"] is not None:
        return server_config["reading_interval"]
    return getattr(config, 'READING_INTERVAL', 10)


def main():
    import config
    connect_wifi()
    if not sta_if.isconnected():
        print("WiFi connection failed. Exiting.")
        return

    # Start update server for push deploys
    update_srv = None
    try:
        from update_server import UpdateServer
        deploy_token = getattr(config, 'DEPLOY_TOKEN', None)
        deploy_port = getattr(config, 'DEPLOY_PORT', 8266)
        if deploy_token and deploy_token != "changeme":
            update_srv = UpdateServer(deploy_token, deploy_port)
            update_srv.start()
        else:
            print("WARNING: DEPLOY_TOKEN not set or is default, update server disabled")
    except Exception as e:
        print(f"Could not start update server: {e}")

    print("WiFi connected. Waiting 5 seconds before pinging server...")
    time.sleep(5)

    if not ping_server():
        print("Server is not reachable. Exiting.")
        return

    device_id = register_with_server()
    if not device_id:
        print("Failed to register device. Exiting.")
        return

    # Initialize real ADC sensors from config.SENSOR_PINS
    sensors = setup_sensors()
    if not sensors:
        print("No sensors initialized. Check SENSOR_PINS in config.")
        return

    # Register each sensor with the backend
    registered_sensors = []
    for s in sensors:
        sensor_id = register_sensor(device_id, s["name"], s["pin"])
        if sensor_id:
            registered_sensors.append({
                "sensor_id": s["pin"],
                "adc": s["adc"],
                "pin": s["pin"],
                "name": s["name"]
            })

    if not registered_sensors:
        print("No sensors registered with server. Exiting.")
        return

    # Initialize OLED display (optional — won't fail if not wired)
    display = None
    try:
        from display import Display
        display = Display()
        if display.available:
            print("OLED display initialized")
            display.show_status("Connected", f"{len(registered_sensors)} sensor(s)")
        else:
            display = None
    except Exception as e:
        print(f"Display not available: {e}")

    # Initial config sync via heartbeat before main loop
    heartbeat_data = send_heartbeat(device_id)
    apply_server_config(heartbeat_data, registered_sensors)

    last_reading_time = 0
    last_heartbeat_time = time.time()

    while True:
        # Check for incoming deploy requests (non-blocking)
        if update_srv:
            update_srv.check()

        if not ensure_wifi():
            time.sleep(5)
            continue

        current_time = time.time()

        # Send readings at dynamic interval
        if current_time - last_reading_time >= get_reading_interval():
            readings_data = []
            for s in registered_sensors:
                moisture, raw = read_moisture(s["adc"])
                print(f"GPIO{s['pin']}: {moisture}% (raw ADC: {raw})")
                send_moisture_reading(device_id, s["sensor_id"], moisture, raw_adc=raw)

                # Compute display moisture using server calibration if available
                sc = server_config["sensors"].get(s["sensor_id"])
                display_moisture = moisture
                if sc and raw is not None and sc.get("calibration_dry") is not None and sc.get("calibration_wet") is not None:
                    dry = sc["calibration_dry"]
                    wet = sc["calibration_wet"]
                    if dry != wet:
                        display_moisture = max(0.0, min(100.0, round(((dry - raw) / (dry - wet)) * 100.0, 1)))

                # Determine alert state using synced thresholds
                alert = False
                if sc:
                    if sc.get("threshold_min") is not None and display_moisture < sc["threshold_min"]:
                        alert = True
                    if sc.get("threshold_max") is not None and display_moisture > sc["threshold_max"]:
                        alert = True

                display_name = s.get("server_name") or s["name"]
                readings_data.append({
                    "name": display_name,
                    "moisture": display_moisture,
                    "alert": alert,
                    "pin": s["pin"],
                })

            if display:
                display.show_readings_enhanced(readings_data, config.DEVICE_NAME)

            last_reading_time = current_time

        # Heartbeat at dedicated interval
        if current_time - last_heartbeat_time >= HEARTBEAT_INTERVAL:
            hb_data = send_heartbeat(device_id)
            apply_server_config(hb_data, registered_sensors)
            last_heartbeat_time = current_time

        time.sleep(1)


if __name__ == "__main__":
    try:
        check_factory_reset()
        if is_configured():
            main()
        else:
            print("Device not configured. Starting captive portal...")
            import captive_portal
            captive_portal.run_portal()
    except KeyboardInterrupt:
        print("Program terminated by user")
    finally:
        print("Exiting program")

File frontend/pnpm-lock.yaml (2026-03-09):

lockfileVersion: '9.0'

settings:
  autoInstallPeers: true
  excludeLinksFromLockfile: false

importers:

  .:
    dependencies:
      '@radix-ui/react-avatar':
        specifier: ^1.1.0
        version: 1.1.11(@types/react-dom@18.3.7(@types/react@18.3.28))(@types/react@18.3.28)(react-dom@18.3.1(react@18.3.1))(react@18.3.1)
      '@radix-ui/react-dialog':
        specifier: ^1.1.1
        version: 1.1.15(@types/react-dom@18.3.7(@types/react@18.3.28))(@types/react@18.3.28)(react-dom@18.3.1(react@18.3.1))(react@18.3.1)
      '@radix-ui/react-dropdown-menu':
        specifier: ^2.1.1
        version: 2.1.16(@types/react-dom@18.3.7(@types/react@18.3.28))(@types/react@18.3.28)(react-dom@18.3.1(react@18.3.1))(react@18.3.1)
      '@radix-ui/react-progress':
        specifier: ^1.1.0
        version: 1.1.8(@types/react-dom@18.3.7(@types/react@18.3.28))(@types/react@18.3.28)(react-dom@18.3.1(react@18.3.1))(react@18.3.1)
      '@radix-ui/react-scroll-area':
        specifier: ^1.1.0
        version: 1.2.10(@types/react-dom@18.3.7(@types/react@18.3.28))(@types/react@18.3.28)(react-dom@18.3.1(react@18.3.1))(react@18.3.1)
      '@radix-ui/react-toast':
        specifier: ^1.2.1
        version: 1.2.15(@types/react-dom@18.3.7(@types/react@18.3.28))(@types/react@18.3.28)(react-dom@18.3.1(react@18.3.1))(react@18.3.1)
      '@radix-ui/react-tooltip':
        specifier: ^1.1.2
        version: 1.2.8(@types/react-dom@18.3.7(@types/react@18.3.28))(@types/react@18.3.28)(react-dom@18.3.1(react@18.3.1))(react@18.3.1)
      axios:
        specifier: ^1.7.7
        version: 1.13.6
      react:
        specifier: ^18.3.1
        version: 18.3.1
      react-dom:
        specifier: ^18.3.1
        version: 18.3.1(react@18.3.1)
      react-router-dom:
        specifier: ^6.26.2
        version: 6.30.3(react-dom@18.3.1(react@18.3.1))(react@18.3.1)
      recharts:
        specifier: ^2.12.7
        version: 2.15.4(react-dom@18.3.1(react@18.3.1))(react@18.3.1)
    devDependencies:
      '@eslint/js':
        specifier: ^9.9.0
        version: 9.39.4
      '@heroicons/react':
        specifier: ^2.1.5
        version: 2.2.0(react@18.3.1)
      '@types/node':
        specifier: ^22.5.5
        version: 22.19.15
      '@types/react':
        specifier: ^18.3.3
        version: 18.3.28
      '@types/react-dom':
        specifier: ^18.3.0
        version: 18.3.7(@types/react@18.3.28)
      '@vitejs/plugin-react':
        specifier: ^4.3.1
        version: 4.7.0(vite@5.4.21(@types/node@22.19.15)(terser@5.46.0))
      autoprefixer:
        specifier: ^10.4.20
        version: 10.4.27(postcss@8.5.8)
      eslint:
        specifier: ^9.9.0
        version: 9.39.4(jiti@1.21.7)
      eslint-plugin-react-hooks:
        specifier: ^5.1.0-rc.0
        version: 5.2.0(eslint@9.39.4(jiti@1.21.7))
      eslint-plugin-react-refresh:
        specifier: ^0.4.9
        version: 0.4.26(eslint@9.39.4(jiti@1.21.7))
      globals:
        specifier: ^15.9.0
        version: 15.15.0
      postcss:
        specifier: ^8.4.47
        version: 8.5.8
      tailwindcss:
        specifier: ^3.4.12
        version: 3.4.19
      typescript:
        specifier: ^5.5.3
        version: 5.9.3
      typescript-eslint:
        specifier: ^8.0.1
        version: 8.56.1(eslint@9.39.4(jiti@1.21.7))(typescript@5.9.3)
      vite:
        specifier: ^5.4.1
        version: 5.4.21(@types/node@22.19.15)(terser@5.46.0)
      vite-plugin-pwa:
        specifier: ^1.2.0
        version: 1.2.0(vite@5.4.21(@types/node@22.19.15)(terser@5.46.0))(workbox-build@7.4.0(@types/babel__core@7.20.5))(workbox-window@7.4.0)
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

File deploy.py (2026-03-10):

#!/usr/bin/env python3
"""Push deploy MicroPython source files to all registered ESP32 devices over the LAN."""

import argparse
import hashlib
import os
import subprocess
import sys

try:
    import requests
except ImportError:
    print("ERROR: 'requests' library is required. Install with: pip install requests")
    sys.exit(1)

SOURCE_DIR = "embeded-src"
EXCLUDED_FILES = {"config.py", "config.py.example"}
DEFAULT_DEVICE_PORT = 8266
DEFAULT_SERVER = os.getenv("DEPLOY_SERVER", "http://192.168.70.222:8000")


def get_git_commit():
    try:
        result = subprocess.run(
            ["git", "rev-parse", "--short=12", "HEAD"],
            capture_output=True, text=True, check=True
        )
        return result.stdout.strip()
    except (subprocess.CalledProcessError, FileNotFoundError):
        return None


def has_uncommitted_changes():
    try:
        result = subprocess.run(
            ["git", "status", "--porcelain"],
            capture_output=True, text=True, check=True
        )
        return bool(result.stdout.strip())
    except (subprocess.CalledProcessError, FileNotFoundError):
        return False


def sha256_file(filepath):
    h = hashlib.sha256()
    with open(filepath, "rb") as f:
        while True:
            chunk = f.read(4096)
            if not chunk:
                break
            h.update(chunk)
    return h.hexdigest()


def collect_files():
    files = []
    for name in os.listdir(SOURCE_DIR):
        if not name.endswith(".py"):
            continue
        if name in EXCLUDED_FILES:
            continue
        path = os.path.join(SOURCE_DIR, name)
        if not os.path.isfile(path):
            continue
        checksum = sha256_file(path)
        size = os.path.getsize(path)
        files.append({"name": name, "path": path, "checksum": checksum, "size": size})
    files.sort(key=lambda f: f["name"])
    return files


def get_devices(server_url, api_key=None):
    headers = {}
    if api_key:
        headers["X-API-Key"] = api_key
    resp = requests.get(f"{server_url}/devices/", headers=headers, timeout=10)
    resp.raise_for_status()
    return resp.json()


def push_file(device_ip, port, token, filepath, filename, checksum):
    with open(filepath, "rb") as f:
        content = f.read()
    resp = requests.post(
        f"http://{device_ip}:{port}/push",
        data=content,
        headers={
            "X-Deploy-Token": token,
            "X-Filename": filename,
            "X-Checksum": checksum,
            "Content-Length": str(len(content)),
        },
        timeout=30,
    )
    return resp.status_code, resp.text


def apply_update(device_ip, port, token, commit, filenames):
    import json
    resp = requests.post(
        f"http://{device_ip}:{port}/apply",
        data=json.dumps({"commit": commit, "files": filenames}),
        headers={
            "X-Deploy-Token": token,
            "Content-Type": "application/json",
        },
        timeout=30,
    )
    return resp.status_code, resp.text


def main():
    parser = argparse.ArgumentParser(description="Push deploy MicroPython files to ESP32 devices.")
    parser.add_argument("--server", default=DEFAULT_SERVER, help=f"Backend server URL (default: {DEFAULT_SERVER})")
    parser.add_argument("--port", type=int, default=DEFAULT_DEVICE_PORT, help=f"Device update server port (default: {DEFAULT_DEVICE_PORT})")
    parser.add_argument("--force", action="store_true", help="Proceed even with uncommitted changes")
    parser.add_argument("--dry-run", action="store_true", help="Show what would be deployed without pushing")
    parser.add_argument("--api-key", default=os.getenv("DEPLOY_API_KEY"), help="API key for backend authentication (default: DEPLOY_API_KEY env)")
    args = parser.parse_args()

    if not args.api_key:
        print("ERROR: DEPLOY_API_KEY env var or --api-key argument required.")
        sys.exit(1)

    # Get git commit
    commit = get_git_commit()
    if not commit:
        print("WARNING: Could not determine git commit hash")
        commit = "unknown"
    else:
        print(f"Git commit: {commit}")

    # Check for uncommitted changes
    if has_uncommitted_changes():
        if args.force:
            print("WARNING: Deploying with uncommitted changes (--force)")
        else:
            print("ERROR: Uncommitted changes detected. Commit first or use --force.")
            sys.exit(1)

    # Collect files
    files = collect_files()
    if not files:
        print(f"ERROR: No .py files found in {SOURCE_DIR}/")
        sys.exit(1)

    print(f"\nFiles to deploy ({len(files)}):")
    for f in files:
        print(f"  {f['name']:30s} {f['size']:>6d} bytes  {f['checksum'][:12]}...")

    # Get device list from backend
    print(f"\nFetching devices from {args.server}...")
    try:
        devices = get_devices(args.server, args.api_key)
    except Exception as e:
        print(f"ERROR: Could not fetch devices: {e}")
        sys.exit(1)

    # Filter to devices with IP and deploy_token
    targets = []
    for d in devices:
        ip = d.get("ip_address")
        token = d.get("deploy_token")
        if ip and token:
            targets.append({"name": d["name"], "device_id": d["device_id"], "ip": ip, "token": token})
        else:
            reason = []
            if not ip:
                reason.append("no IP")
            if not token:
                reason.append("no deploy token")
            print(f"  Skipping {d['name']} ({', '.join(reason)})")

    if not targets:
        print("No deployable devices found (need IP address and deploy token).")
        sys.exit(0)

    print(f"\nTargets ({len(targets)}):")
    for t in targets:
        print(f"  {t['name']:20s} {t['ip']:15s} token={t['token'][:8]}...")

    if args.dry_run:
        print("\n[DRY RUN] No files pushed.")
        return

    # Deploy to each device
    print()
    results = []
    filenames = [f["name"] for f in files]

    for t in targets:
        name = t["name"]
        ip = t["ip"]
        token = t["token"]
        print(f"Deploying to {name} ({ip})...")

        try:
            # Push each file
            all_ok = True
            for f in files:
                status, text = push_file(ip, args.port, token, f["path"], f["name"], f["checksum"])
                if status != 200:
                    print(f"  FAIL {f['name']}: {status} {text}")
                    all_ok = False
                    break
                else:
                    print(f"  OK   {f['name']}")

            if not all_ok:
                results.append((name, "FAILED", "File push failed"))
                continue
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

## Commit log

2024-09-20 Rearranging project structure to fix imports
    [main.py]
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2024-09-20 Fixes tailwind config and cors
    [main.py]
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2026-03-08 Refactor backend, fix type bugs, and add OTA firmware update support
    Extract shared get_db() dependency, fix deprecated datetime.utcnow() calls,
    fix device_id type mismatches (int->str) across backend/frontend, remove
    duplicate sensor route, and normalize all handlers to async. Add Device
    heartbeat/firmware fields, Firmware model, OTA endpoints (upload, manifest,
    file serving, version check), ESP32 WiFi reconnection, HTTP retry with
    backoff, MAC-based registration, and full OTA update flow with checksum
    verification and rollback. Add firmware management page to frontend with
    device online/offline status indicators.
    [main.py]
2026-03-08 Add captive portal WiFi provisioning for ESP32 devices
    Implements a complete captive portal flow so new ESP32 devices can be
    configured from a phone/laptop without USB access after initial firmware
    flash. Includes factory reset via BOOT button, WiFi failure fallback to
    AP mode, device delete endpoint with cascade cleanup, and updated
    frontend with accurate setup instructions and auto-refresh.
    [captive_portal.py, main.py]
2026-03-08 Add cross-platform ESP32 flash script and normalize line endings
    Add flash_esp.py that auto-detects the serial port and handles erase,
    firmware flash, and source file upload in one step. Add .gitattributes
    to normalize line endings (LF in repo) and prevent CRLF/LF diffs in
    WSL/Windows environments. Update firmware README with usage instructions.
    [flash_esp.py]
2026-03-09 Replace simulated sensors with real ADC reads and add OLED display support
    Swap random sensor data for actual ESP32 ADC1 reads with 10-sample
    averaging and configurable dry/wet calibration. Support up to 6
    moisture sensors per ESP32 (GPIOs 32, 33, 34, 35, 36, 39). Add
    optional SSD1306 OLED display module with graceful fallback. Document
    full hardware pinout for Elecbee/icomcu sensors and GME12864 display.
    [captive_portal.py, display.py, flash_esp.py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]
2026-03-09 Fix sensor registration and reading pipeline to use GPIO pin as sensor_id
    - ESP32: send sensor_id (GPIO pin) in register_sensor(), use pin number for readings
    - Backend: return existing sensor on duplicate registration instead of 400 error
    - Backend: resolve sensor_id (GPIO pin) to DB PK before querying readings
    - Backend: rename get_readings_by_sensor param to sensor_db_id for clarity
    - Frontend: use sensor.sensor_id in Readings dropdown to match API route
    [main.py]
2026-03-09 Add server-side sensor calibration system with frontend wizard
    ESP32 now sends raw ADC values alongside moisture readings. Backend stores
    per-sensor calibration points (dry/wet) and computes correct moisture
    percentages server-side, fixing the always-100% issue from hardcoded defaults.
    Frontend adds a 3-step calibration wizard on the Sensors page and a Raw ADC
    column on the Readings page. Old firmware without raw_adc continues to work.
    [main.py]
2026-03-09 Add --sync-only flag to flash_esp.py for quick code uploads
    Allows uploading source files to ESP32 without erasing flash and
    reflashing MicroPython firmware.
2026-03-09 Dashboard modernization: plant-centric UI with zones, alerts, and drill-down
    Shifts the app from device-centric to plant-centric. Users can now see
    which plants need water at a glance, organize sensors by zone/room, rename
    plants inline, set thresholds, and get prominent alert notifications.
    Backend:
    - Zone model with sensor grouping and full CRUD API
    - Dashboard summary endpoint (stats, per-sensor moisture, sparklines, trends)
    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
2026-03-09 Add bidirectional config sync, editable settings, and enhanced OLED display
    Server-side SystemConfig model with GET/PUT /config/ endpoints replaces
    hardcoded settings. Heartbeat response now carries system config + per-sensor
    config (names, calibration, thresholds) to ESP32 devices with zero extra
    HTTP requests. Settings page has editable inputs with validation and save.
    Dashboard device timeout is now dynamic. ESP32 parses heartbeat response
    for config sync with fallback to local config. OLED display shows server
    names, alert indicators, and paginated sensor list.
    [display.py, main.py]
2026-03-09 Remove unused code, deps, and modernize Pydantic config
    - Backend: remove 9 unused pip packages (bcrypt, passlib, python-jose, etc.)
    - Backend: remove unused uuid import from crud.py
    - Backend: replace Pydantic v1 Config classes with v2 model_config
    - Backend: fix device_id bug and deprecated utcnow() in populate_test_data.py
    - Frontend: delete unused DeviceCard component
    - Frontend: remove unused API functions (createDevice, createSensor, getLatestFirmware)
    - Frontend: remove unused type definitions (DeviceCreate, SensorCreate)
    - Frontend: remove unused npm packages (clsx, tailwind-merge, @types/react-router-dom)
    - Embedded: remove dead show_readings() and clear() methods from display.py
    C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
    [display.py, pnpm-lock.yaml]
2026-03-09 Add watering log, plant notes, and auto-watering detection
    Full-stack implementation of the watering-log feature group (7 features):
    - WateringLog model with method enum (manual/auto/rain) and CRUD
    - REST API: POST/GET/DELETE /watering-logs/ with sensor filtering
    - Log Watering modal and watering history timeline on PlantDetail
    - Plant notes (click-to-edit) on PlantDetail page
    - Auto-detect watering from moisture spikes (per-sensor toggle)
    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
2026-03-09 Add push notifications via ntfy for alerts and device offline events
    Integrates ntfy push notification service so moisture alerts and device
    offline events are delivered to the user's phone instead of requiring
    dashboard checks. Includes backend notification service, config model
    extensions, test endpoint, and Settings UI with toggle/topic/test button.
2026-03-09 Add historical data & insights: aggregated readings, drying rate, CSV export, and time range controls
    - Aggregated readings API (daily/weekly) with avg/min/max per period
    - Drying rate API using linear regression with post-watering exclusion
    - CSV export endpoint with frontend download trigger
    - Time range selector (24h/7d/30d/all) on Readings page with aggregated chart bands
    - PlantInsights card on PlantDetail showing avg moisture, drying rate, days until dry, waterings this month
    - SensorReadingsGraph dual-mode: raw readings or aggregated data with min/max shaded area
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2026-03-09 Expand hardware docs with full pin reference, OLED display, sensors, and calibration
2026-03-09 Fix default dry calibration value to 0 in hardware docs
2026-03-09 Fix default ADC_DRY calibration value from 3500 to 0
    [captive_portal.py, main.py]
2026-03-09 Add inline rename for devices and sensors, fix plant detail header
    - Add PATCH /devices/{device_id} endpoint for renaming devices
    - Add inline rename (InlineEdit) to /devices and /sensors list pages
    - Fix plant detail "on" label to show device name instead of device_id
    - Fix zone select dropdown padding so chevron doesn't overlap text
2026-03-09 Add dashboard enhancements: sort/filter, weather widget, quick actions, kiosk mode
    Dashboard sort & filter toolbar with localStorage persistence (zone/moisture/name
    sort, all/needs-water/healthy filter). Weather widget using Open-Meteo API with
    lat/lon from Settings. Quick action overlay on PlantCard hover/tap (log watering,
    threshold, history). Full-screen kiosk mode with auto-cycling zones and Escape to
    exit. Backend: weather_latitude/longitude on SystemConfig with DB migration.
2026-03-09 Add mobile experience: collapsible sidebar, bottom nav, PWA support
    - MobileNavContext tracks viewport width and sidebar state
    - Sidebar becomes slide-in overlay on mobile (<768px) with backdrop
    - Hamburger menu button in navbar (mobile only), hide kiosk/status on mobile
    - Bottom navigation bar with Dashboard, Alerts, Settings + alert badge
    - PlantCard mobile optimizations: larger moisture text, taller bar, bigger tap targets
    - PWA via vite-plugin-pwa: manifest, service worker, offline API caching
    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
2026-03-09 Add PCB design for sensor breakout board
    KiCad project with netlist generator, PCB layout, and Gerber output
    files ready for JLCPCB ordering. Board connects ESP32 DevKit V1,
    SSD1306 OLED, and 5 JST-XH moisture sensor connectors with shared
    3V3/GND rails. README includes full parts list, ordering settings,
    and assembly instructions.
    [plant_water_array-B_Cu.gbr, plant_water_array-B_Mask.gbr, plant_water_array-B_Paste.gbr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]
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2026-03-09 Add database backup & maintenance: backup download, DB stats, auto-cleanup
    - GET /admin/backup endpoint using SQLite online backup API for safe live copies
    - GET /admin/stats endpoint with total readings, DB size, readings/day, oldest reading
    - retention_days field on SystemConfig (default 90) with auto-cleanup on startup
    - Database Health section on Settings page showing key metrics
    - Download Backup button and configurable retention settings in UI
    - Manual cleanup preserved for ad-hoc deletion
2026-03-09 Add sensor & device diagnostics: heartbeat logging, health indicators, debug view
    - HeartbeatLog model with device_id, timestamp, IP, firmware version
    - Heartbeat logging hooked into existing heartbeat endpoint
    - GET /devices/{device_id} and GET /devices/{device_id}/heartbeats endpoints
    - Sensor health computation (reading frequency, ADC stuck detection, flatline)
    - GET /sensors/health/batch and GET /sensors/{id}/health endpoints
    - Device Detail page with info card, sensors list, heartbeat history, uptime
    - Health column on Sensors page with OK/Stale/ADC issue/Flatline badges
    - Debug toggle on PlantDetail with dual Y-axis chart and raw ADC values table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
2026-03-09 Add env config & Docker: dotenv support, VITE_API_URL, docker-compose
    Replace all hardcoded config with environment variables:
    - DATABASE_URL, HOST, PORT, CORS_ORIGINS, FIRMWARE_STORAGE_PATH in backend
    - VITE_API_URL in frontend (import.meta.env)
    - CORS_ORIGINS parsed as comma-separated list (default '*')
    Add Docker containerization for Coolify deployment:
    - Backend Dockerfile (python:3.12-slim, /data volume for DB + firmware)
    - Frontend Dockerfile (multi-stage node build + nginx, SPA routing)
    - docker-compose.yml with named volume and configurable ports
    [main.py]
2026-03-09 Add multi-plant comparison: compare page, zone charts, multi-sensor API
    - GET /readings/compare endpoint (multi-sensor query, hourly aggregation for >24h)
    - Compare page with sensor multi-select grouped by zone, time range picker, overlaid LineChart
    - Compare added to sidebar navigation between Dashboard and Alerts
    - Zone aggregate chart toggle on dashboard ZoneSection (24h average moisture)
2026-03-10 Fix OLED color split, add moisture bars; fix modal z-index & animations
    Move OLED sensor rows to y=16 (blue zone) to fix yellow/blue color
    split on SSD1306. Add proportional moisture fill bars per sensor row.
    Fix modal overlay/content z-index stacking, use centered slide-up
    animation, and clean up PlantCard layout.
    [display.py]
2026-03-10 Replace pull-based OTA with CLI push deploy
    Remove the firmware upload/download system (Firmware model, router, page)
    and replace with a push deploy model: `python deploy.py` reads .py files
    from embeded-src/, fetches device IPs and deploy tokens from the backend
    API, and pushes code directly to each device's update server (port 8266).
    Devices run a lightweight non-blocking HTTP server (update_server.py) that
    receives files with token auth and SHA-256 verification, stages them as
    .new files, then atomically swaps them in on apply. Version tracking uses
    git commit hash written to _version.py on each deploy.
    Each device gets a unique DEPLOY_TOKEN during captive portal provisioning,
    stored in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
    [captive_portal.py, deploy.py, flash_esp.py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]
2026-03-10 Fix stale readings on PlantDetail: add ORDER BY before LIMIT
    get_readings_by_sensor() applied LIMIT without ORDER BY, so SQLite
    returned an arbitrary subset of rows. The "current reading" on the
    PlantDetail page could be hours old. Sort DESC by timestamp before
    limiting, then reverse for chronological order.
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2026-03-10 Use bind mount for backend data (NAS-backed storage)
    Replace Docker named volume with configurable DATA_DIR bind mount.
    Set DATA_DIR=/mnt/nas1/appdata/plant-water-array in Coolify to
    store the SQLite DB on nas1 via NFS.
2026-03-10 Hardcode NAS bind mount path for Coolify compatibility
    Coolify doesn't handle shell-style variable defaults in compose.
    Use absolute path directly instead of ${DATA_DIR:-./data}.
2026-03-10 Rewrite README with accurate dev commands and deployment docs
    Replace outdated generic README with current project state:
    development commands, architecture overview, Coolify deployment
    details, NAS-backed storage, ESP32 LAN access, and data flow.
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2026-03-13 Fix backend crash: load dotenv before checking required env vars
    auth.py reads ADMIN_PASSWORD, DEPLOY_API_KEY, and DEVICE_API_KEY at
    import time but never called load_dotenv(). Because auth.py is imported
    before database.py (which had the load_dotenv call), the .env file was
    never loaded in time, causing a RuntimeError on startup.
